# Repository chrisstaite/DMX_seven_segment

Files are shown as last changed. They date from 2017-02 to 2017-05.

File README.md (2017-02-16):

# DMX Seven Segment
An implementation of a DMX controller using a seven segment display
on an ATmega32A.

This utilises a small board with three buttons for up/down/channel
and a seven segment display to show the value.  A WS2812 shows the
RGB value.

All of the code is written to be run directly on the ATmega32A
without any external libraries other than AVR-Libc.

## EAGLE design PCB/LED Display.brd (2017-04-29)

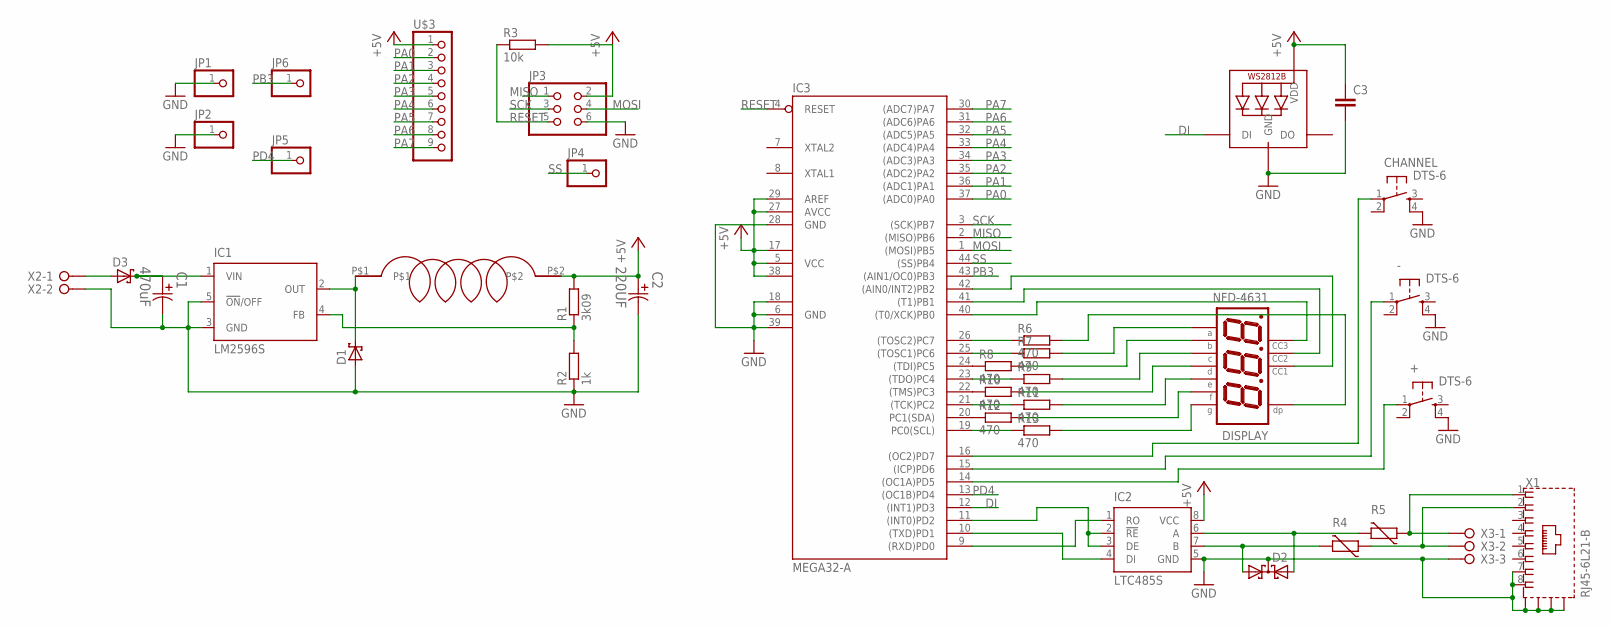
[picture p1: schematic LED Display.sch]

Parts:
+: DTS-6
-: DTS-6
C1: 470uF; CAPAE1030X1050N
C2: 220UF; CAPAE660X610N
C3: C-EUC0805; C0805
CHANNEL: DTS-6
D1, D3: MBRS130LT3; SMB
D2: BAS40-05; SOT23
DISPLAY: NFD-4631; NFD-5631
IC1: LM2596S; TO263-5
IC2: LTC485S; SOIC8
IC3: MEGA32-A; TQFP44
JP1, JP2, JP5, JP6: PINHD-1X1CB; 1X01-CLEANBIG
JP3: PINHD-2X3; 2X03
JP4: PINHD-1X1; 1X01
LED1: WS2812B5050; WS2812B
R1: 3k09; M0805
R2: 1k; M0805
R3: 10k; M0805
R4, R5: VARISTORCN1812; CT/CN1812; FARNELL 1652168
R6, R7, R8, R9, R10, R11, R12, R13: 470; M0805
U$1: SRN8040
U$3: PINHD-1X9; 1X09-BIG
X1: RJ45-6L21-B; RJ45-SHIELD1
X2: W237-02P; W237-132
X3: W237-03P; W237-133

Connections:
+5V: C2.1, C3.1, IC2.8 (VCC), IC3.5 (VCC), IC3.17 (VCC1), IC3.27 (AVCC), IC3.29 (AREF), IC3.38 (VCC2), JP3.2, LED1.1-VDD (VDD), R1.2, R3.2, U$1.P$2, U$3.1
DI: IC3.12 ((INT1)PD3), LED1.4-DIN (DI)
GND: +.4, -.4, C1.2, C2.2, C3.2, CHANNEL.4, D1.A, D2.3 (C), IC1.3 (GND), IC1.5 (!ON!/OFF), IC2.5 (GND), IC3.6 (GND), IC3.18 (GND1), IC3.28 (GND), IC3.39 (GND2), JP1.1, JP2.1, JP3.6, LED1.3-GND (GND), R2.1, X1.7, X1.8, X1.S1 (S), X1.S2 (S), X1.S3 (S), X1.S4 (S), X2.2, X3.3
MISO: IC3.2 ((MISO)PB6), JP3.1
MOSI: IC3.1 ((MOSI)PB5), JP3.4
unnamed: C1.1, D3.C, IC1.1 (VIN)
unnamed: D2.1 (A1), IC2.7 (B), R4.2
unnamed: IC1.4 (FB), R1.1, R2.2
unnamed: D1.C, IC1.2 (OUT), U$1.P$1
unnamed: D2.2 (A2), IC2.6 (A), R5.2
unnamed: IC2.2 (!RE), IC2.3 (DE), IC3.11 ((INT0)PD2)
unnamed: IC2.1 (RO), IC3.9 ((RXD)PD0)
unnamed: IC2.4 (DI), IC3.10 ((TXD)PD1)
unnamed: R4.1, X1.2, X3.2
unnamed: R5.1, X1.1, X3.1
unnamed: IC3.26 ((TOSC2)PC7), R6.1
unnamed: +.1, IC3.14 ((OC1A)PD5)
unnamed: DISPLAY.P$5 (P$G), R13.2
unnamed: DISPLAY.P$10 (P$F), R12.2
unnamed: DISPLAY.P$1 (P$E), R11.2
unnamed: DISPLAY.P$2 (P$D), R10.2
unnamed: DISPLAY.P$4 (P$C), R9.2
unnamed: DISPLAY.P$7 (P$B), R8.2
unnamed: DISPLAY.P$11 (P$A), R7.2
unnamed: DISPLAY.P$3 (P$DP), R6.2
unnamed: DISPLAY.P$12 (P$CC1), IC3.42 ((AIN0/INT2)PB2)
unnamed: DISPLAY.P$9 (P$CC2), IC3.41 ((T1)PB1)
unnamed: -.1, IC3.15 ((ICP)PD6)
unnamed: CHANNEL.1, IC3.16 ((OC2)PD7)
unnamed: IC3.24 ((TDI)PC5), R8.1
unnamed: IC3.22 ((TMS)PC3), R10.1
unnamed: IC3.20 (PC1(SDA)), R12.1
unnamed: IC3.19 (PC0(SCL)), R13.1
unnamed: IC3.21 ((TCK)PC2), R11.1
unnamed: IC3.23 ((TDO)PC4), R9.1
unnamed: IC3.25 ((TOSC1)PC6), R7.1
unnamed: DISPLAY.P$8 (P$CC3), IC3.40 ((T0/XCK)PB0)
unnamed: D3.A, X2.1
PA0: IC3.37 ((ADC0)PA0), U$3.2
PA1: IC3.36 ((ADC1)PA1), U$3.3
PA2: IC3.35 ((ADC2)PA2), U$3.4
PA3: IC3.34 ((ADC3)PA3), U$3.5
PA4: IC3.33 ((ADC4)PA4), U$3.6
PA5: IC3.32 ((ADC5)PA5), U$3.7
PA6: IC3.31 ((ADC6)PA6), U$3.8
PA7: IC3.30 ((ADC7)PA7), U$3.9
PB3: IC3.43 ((AIN1/OC0)PB3), JP6.1
PD4: IC3.13 ((OC1B)PD4), JP5.1
RESET: IC3.4 (RESET), JP3.5, R3.1
SCK: IC3.3 ((SCK)PB7), JP3.3
SS: IC3.44 ((SS)PB4), JP4.1

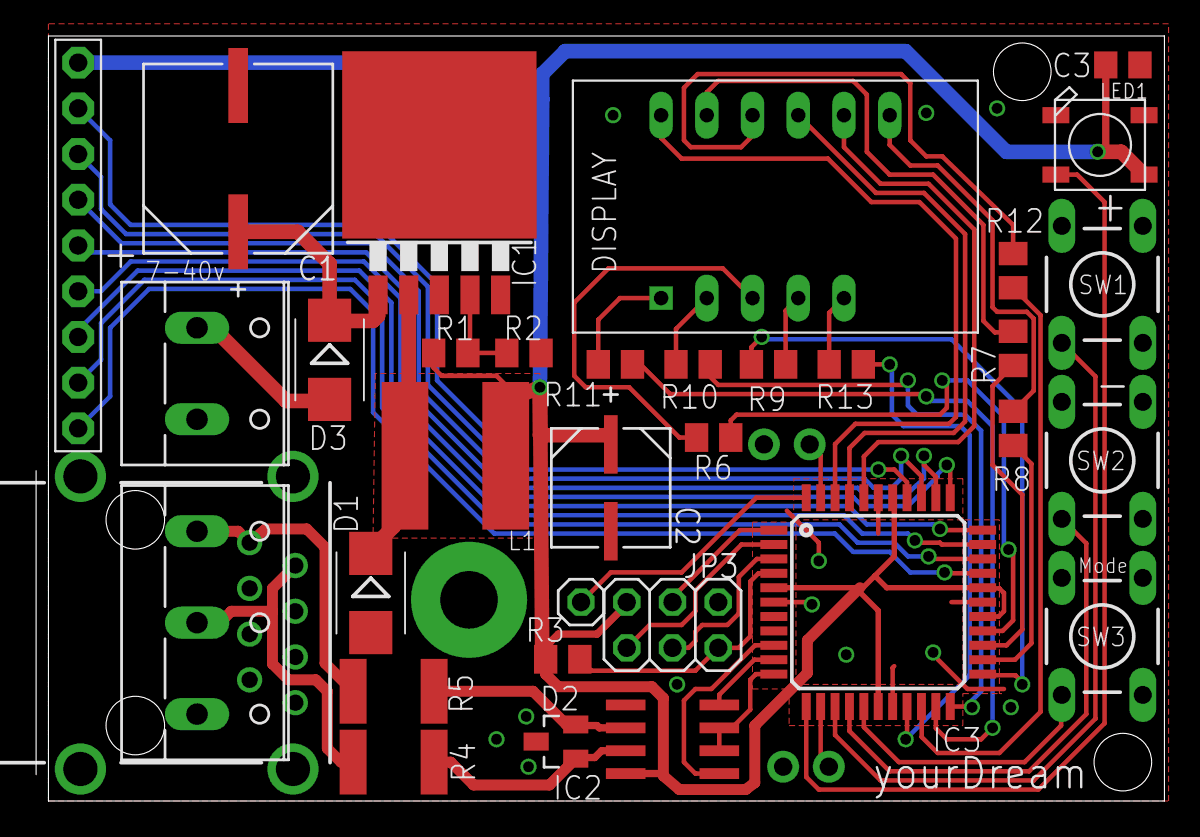
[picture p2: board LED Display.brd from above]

Board: 2 copper layers, 62.7 x 42.5 mm, 38 parts (0 on the bottom side), 51 nets.

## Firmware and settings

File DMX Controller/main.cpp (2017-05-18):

#include "pin.h"
#include "port.h"
#include "const_pin.h"
#include "seven_segment.h"
#include "seven_segment_array.h"
#include "button.h"
#include "ws2812.h"
#include "dmx.h"
#include "ms_timer.h"
#include "eeprom.h"
#include "timed_event.h"
#include "save_event.h"
#include "rgb_display_event.h"
#include "repeat_event.h"
#include "latched_button.h"
#include "mode_event.h"
#include "value_display_event.h"
#include "controller.h"

#include <avr/interrupt.h>
#include <avr/eeprom.h>

namespace {

/// The number of milliseconds between the last change and
/// saving the values to the EEPROM
constexpr uint16_t SAVE_INTERVAL = 10000;

/// The number of milliseconds between the changing mode and
/// displaying the selected colour on the LED
constexpr uint16_t RGB_INTERVAL = 2000;

/// The number of milliseconds between the chaning mode and
/// displaying the current channel value on the display
constexpr uint16_t CHANNEL_SHOW_INTERVAL = 800;

// Configure the buttons
avr::Pin buttonUp{avr::ConstPin<avr::PortD, 5>::toPin()};
avr::Pin buttonDown{avr::ConstPin<avr::PortD, 6>::toPin()};
avr::Pin buttonMode{avr::ConstPin<avr::PortD, 7>::toPin()};
avr::Button up{buttonUp};
avr::Button down{buttonDown};
avr::Button mode{buttonMode};

// Configure the Display
avr::Pin digitSelectors[3] = {
    {avr::ConstPin<avr::PortB, 2>::toPin()},
    {avr::ConstPin<avr::PortB, 1>::toPin()},
    {avr::ConstPin<avr::PortB, 0>::toPin()}
};
led::SevenSegmentArray display{digitSelectors, avr::PortC{}};

// Configure millisecond timer
avr::MsTimer timer{};

// Configure DMX
dmx::Dmx dmxOutput{avr::ConstPin<avr::PortD, 2>{}};

// Configure LED
led::WS2812 ws2812{avr::ConstPin<avr::PortD, 3>{}};

// Set the default EEPROM
uint8_t channelStorage[] EEMEM = { 0, 0, 0, 0 };
// Load the saved values
avr::Eeprom eeprom{channelStorage};

// Create the controller
led::Controller controller{dmxOutput, display};

// Configure colour LED setter
led::RgbDisplayEvent rgbDisplayEvent{ws2812, controller};
avr::TimedEvent rgbDisplayTimer{rgbDisplayEvent};

// Configure timer to show the current value
led::ValueDisplayEvent valueDisplayEvent{controller};
avr::TimedEvent valueDisplayTimer{valueDisplayEvent};

// Configure EEPROM saver
led::SaveEvent saveEvent{eeprom, controller};
avr::TimedEvent saveTimer{saveEvent};

// Configure plus and minus buttons
avr::RepeatEvent<led::Controller, &led::Controller::increase>
    increaseEvent{controller};
avr::RepeatEvent<led::Controller, &led::Controller::decrease>
    decreaseEvent{controller};
avr::TimedEvent increaseTimer{increaseEvent};
avr::TimedEvent decreaseTimer{decreaseEvent};
led::LatchedButton upLatch{up, increaseTimer};
led::LatchedButton downLatch{down, decreaseTimer};

// Configure mode button
led::ModeEvent modeEvent{controller};
avr::TimedEvent modeTimer{modeEvent};
led::LatchedButton modeLatch{mode, modeTimer};

}  // anon namespace

int main()
{
    for (uint8_t i = 0; i < led::ModeEvent::MAX_MODE; ++i)
    {
        dmxOutput.setChannel(i, eeprom[i]);
    }
    rgbDisplayTimer.reset(1);
    controller.setModifierChannel(0);

    // Globally enable interrupts
    sei();

    // The millis on the last loop
    uint16_t lastMillis = 0;
	while (1)
    {
        uint16_t loopMillis = timer.millis();
        if (lastMillis != loopMillis)
        {
            lastMillis = loopMillis;

            (void) saveTimer.tick();
            (void) rgbDisplayTimer.tick();
            (void) valueDisplayTimer.tick();

            if (increaseTimer.tick() || decreaseTimer.tick())
            {
                rgbDisplayTimer.reset(1);
                saveTimer.reset(SAVE_INTERVAL);
                valueDisplayTimer.cancel();
            }

            if (modeTimer.tick())
            {
                uint8_t mode = modeEvent.mode();
                led::RGB ledColour {
                    (mode == 0 || mode == 3) ? static_cast<uint8_t>(255) : static_cast<uint8_t>(0),
                    (mode == 1 || mode == 3) ? static_cast<uint8_t>(255) : static_cast<uint8_t>(0),
                    (mode == 2 || mode == 3) ? static_cast<uint8_t>(255) : static_cast<uint8_t>(0)
                };
                ws2812.sendRgb(&ledColour, 1);
                rgbDisplayTimer.reset(RGB_INTERVAL);

                display.setValue(0, led::SevenSegment::Letters::C);
                display.setValue(1, led::SevenSegment::Letters::H);
                display.setValue(2, mode + 1);
                valueDisplayTimer.reset(CHANNEL_SHOW_INTERVAL);
            }

            upLatch.test();
            downLatch.test();
            modeLatch.test();
        }
	}

    // Never get here or bad things happen (chip stops)
	return 0;
}

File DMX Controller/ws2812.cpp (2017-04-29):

//
//  ws2812.cpp
//  DMX Controller
//
//  Created by Chris Staite on 09/02/2017.
//  Copyright © 2017 Chris Staite. All rights reserved.
//

#include "ws2812.h"
#include "pin.h"

#include <avr/io.h>
#include <avr/interrupt.h>

// Timing in ns
#define w_zeropulse   350
#define w_onepulse    900
#define w_totalperiod 1250

// Fixed cycles used by the inner loop
#define w_fixedlow    2
#define w_fixedhigh   4
#define w_fixedtotal  8   

// Insert NOPs to match the timing, if possible
#define w_zerocycles    (((F_CPU/1000)*w_zeropulse          )/1000000)  // 2.8
#define w_onecycles     (((F_CPU/1000)*w_onepulse    +500000)/1000000)  // 7.7
#define w_totalcycles   (((F_CPU/1000)*w_totalperiod +500000)/1000000)  // 10.5

// w1 - nops between rising edge and falling edge - low
#define w1 (w_zerocycles-w_fixedlow)  // 0.8
// w2   nops between fe low and fe high
#define w2 (w_onecycles-w_fixedhigh-w1)  // 2.9
// w3   nops to complete loop
#define w3 (w_totalcycles-w_fixedtotal-w1-w2)  // -1.2

#if w1>0
  #define w1_nops w1
#else
  #define w1_nops  0
#endif

// The only critical timing parameter is the minimum pulse length of the "0"
// Warn or throw error if this timing can not be met with current F_CPU settings.
#define w_lowtime ((w1_nops+w_fixedlow)*1000000)/(F_CPU/1000)
#if w_lowtime>550
   #error "Light_ws2812: Sorry, the clock speed is too low. Did you set F_CPU correctly?"
#elif w_lowtime>450
   #warning "Light_ws2812: The timing is critical and may only work on WS2812B, not on WS2812(S)."
   #warning "Please consider a higher clockspeed, if possible"
#endif   

#if w2>0
#define w2_nops w2
#else
#define w2_nops  0
#endif

#if w3>0
#define w3_nops w3
#else
#define w3_nops  0
#endif

#define w_nop1  "nop      \n\t"
#define w_nop2  "rjmp .+0 \n\t"
#define w_nop4  w_nop2 w_nop2
#define w_nop8  w_nop4 w_nop4
#define w_nop16 w_nop8 w_nop8

void inline ws2812_sendarray_mask(uint8_t *data,uint16_t datlen,uint8_t maskhi)
{
  uint8_t curbyte,ctr,masklo;
  uint8_t sreg_prev;
  
  DDRA |= maskhi; // Enable output
  
  masklo	=~maskhi&PORTD;
  maskhi |=        PORTD;
  
  sreg_prev=SREG;
  cli();  

  while (datlen--) {
    curbyte=*data++;
    
    asm volatile(
    "       ldi   %0,8  \n\t"
    "loop%=:            \n\t"
    "       out   %2,%3 \n\t"    //  '1' [01] '0' [01] - re
#if (w1_nops&1)
w_nop1
#endif
#if (w1_nops&2)
w_nop2
#endif
#if (w1_nops&4)
w_nop4
#endif
#if (w1_nops&8)
w_nop8
#endif
#if (w1_nops&16)
w_nop16
#endif
    "       sbrs  %1,7  \n\t"    //  '1' [03] '0' [02]
    "       out   %2,%4 \n\t"    //  '1' [--] '0' [03] - fe-low
    "       lsl   %1    \n\t"    //  '1' [04] '0' [04]
#if (w2_nops&1)
  w_nop1
#endif
#if (w2_nops&2)
  w_nop2
#endif
#if (w2_nops&4)
  w_nop4
#endif
#if (w2_nops&8)
  w_nop8
#endif
#if (w2_nops&16)
  w_nop16 
#endif
    "       out   %2,%4 \n\t"    //  '1' [+1] '0' [+1] - fe-high
#if (w3_nops&1)
w_nop1
#endif
#if (w3_nops&2)
w_nop2
#endif
#if (w3_nops&4)
w_nop4
#endif
#if (w3_nops&8)
w_nop8
#endif
#if (w3_nops&16)
w_nop16
#endif

    "       dec   %0    \n\t"    //  '1' [+2] '0' [+2]
    "       brne  loop%=\n\t"    //  '1' [+3] '0' [+4]
    :	"=&d" (ctr)
    :	"r" (curbyte), "I" (_SFR_IO_ADDR(PORTD)), "r" (maskhi), "r" (masklo)
    );
  }
  
  SREG=sreg_prev;
}

namespace led {

void WS2812::sendRgb(RGB* values, uint16_t count)
{
    static_assert(sizeof(RGB) == 3, "RGB structure has been padded");
    ws2812_sendarray_mask(reinterpret_cast<uint8_t*>(values), count * sizeof(RGB), m_mask);
}

}  // namespace led

/*
namespace led {

namespace {

// This routine writes an array of bytes with RGB values to the Dataout pin
// using the fast 800kHz clockless WS2811/2812 protocol.

// Timing in ns
constexpr int32_t ZERO_PULSE_NS   = 400;   //  400 +- 150
constexpr int32_t ONE_PULSE_NS    = 800;   //  800 +- 150
constexpr int32_t TOTAL_PERIOD_NS = 1250;  // 1250 +- 300

// The number of cycles used by the instructions for
// each bit of the loop
constexpr int32_t LOW_CYCLES_USED   = 3;
constexpr int32_t HIGH_CYCLES_USED  = 6;
constexpr int32_t TOTAL_CYCLES_USED = 10;

// Calculate the number of cycles we should be emitting each pulse for
constexpr int32_t ZERO_CYCLES  = ((F_CPU / 1000) *   ZERO_PULSE_NS         ) / 1000000;
// Round up
constexpr int32_t ONE_CYCLES   = ((F_CPU / 1000) *    ONE_PULSE_NS + 500000) / 1000000;
// Round up
constexpr int32_t TOTAL_CYCLES = ((F_CPU / 1000) * TOTAL_PERIOD_NS + 500000) / 1000000;

// Calculate the difference between the cycles used and the optimum
// number of cycles for each stage, ignoring negative numbers
constexpr int32_t ZERO_CYCLES_NOP =
    (ZERO_CYCLES - LOW_CYCLES_USED < 0) ? 0 : (ZERO_CYCLES - LOW_CYCLES_USED);
constexpr int32_t ONE_CYCLES_NOP =
    (ONE_CYCLES - HIGH_CYCLES_USED - (ZERO_CYCLES - LOW_CYCLES_USED) < 0) ? 0 :
    (ONE_CYCLES - HIGH_CYCLES_USED - (ZERO_CYCLES - LOW_CYCLES_USED));
constexpr int32_t FINAL_CYCLES_NOP =
    (TOTAL_CYCLES - TOTAL_CYCLES_USED - (ONE_CYCLES - HIGH_CYCLES_USED) < 0) ? 0 :
    (TOTAL_CYCLES - TOTAL_CYCLES_USED - (ONE_CYCLES - HIGH_CYCLES_USED));

// The only critical timing parameter is the minimum pulse length of the "0"
// Warn or throw error if this timing can not be met with current F_CPU settings.
static_assert(((ZERO_CYCLES_NOP + LOW_CYCLES_USED) * 1000000) / (F_CPU / 1000) <= 550,
              "The clock speed is too low for the WS2812");
static_assert(((ZERO_CYCLES_NOP + LOW_CYCLES_USED) * 1000000) / (F_CPU / 1000) >= 250,
              "The clock speed is too high for the WS2812");

// Here's a nice little template to produce our NOP's based on
// the values we just calculated...
template<int32_t N>
__attribute__((always_inline)) inline void nop()
{
    nop<N-2>();
    nop<2>();
}

template<>
__attribute__((always_inline)) inline void nop<0>()
{
}

template<>
__attribute__((always_inline)) inline void nop<1>()
{
    asm volatile("nop\n\t");
}

template<>
__attribute__((always_inline)) inline void nop<2>()
{
    asm volatile("rjmp .+0\n\t");
}

}  // anon namespace

void WS2812::sendRgb(RGB* values, uint16_t count)
{
    static_assert(sizeof(RGB) == 3, "RGB structure has been padded");
    sendRgb(reinterpret_cast<uint8_t*>(values), count * sizeof(RGB));
}
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

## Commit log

2017-02-16 Initial commit.
    [LED Display.brd, LED Display.sch]
2017-02-16 Fix the DMX and WS2812 implementations.
    [LED Display.brd]
2017-03-05 Fixes for hardware.
    [LED Display.brd, LED Display.sch]
2017-04-29 Numerous fixes.
    [LED Display.brd, LED Display.sch]
2017-04-29 Add fuse setting to flash command.
2017-04-29 Tidy the board.
    [LED Display.brd]
2017-05-18 Fix the orientation of the characters
    [main.cpp]
